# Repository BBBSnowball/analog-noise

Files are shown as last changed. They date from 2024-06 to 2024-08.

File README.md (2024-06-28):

"Completely analog" noise generator
===================================

A friends is very into analog synthesizers. I'm usually more on the digital side.
You can imagine the discussions we sometimes have about this ;-)

He recently baught [this drum synthesizer][1] that supposedly has "some digital
components" but he said that any passive module is "analog enough". What is a
passive module? Anything without a dedicated power supply, i.e. the only power
flowing into it is via its input signals.

Some time later, he mentioned that he doesn't know of any good analog noise generators.

Well.... let the trolling begin :-D

[1]: https://www.errorinstruments.com/a-85227938/bricky-format-standalone-box/po-passive-operator-drum-synth/

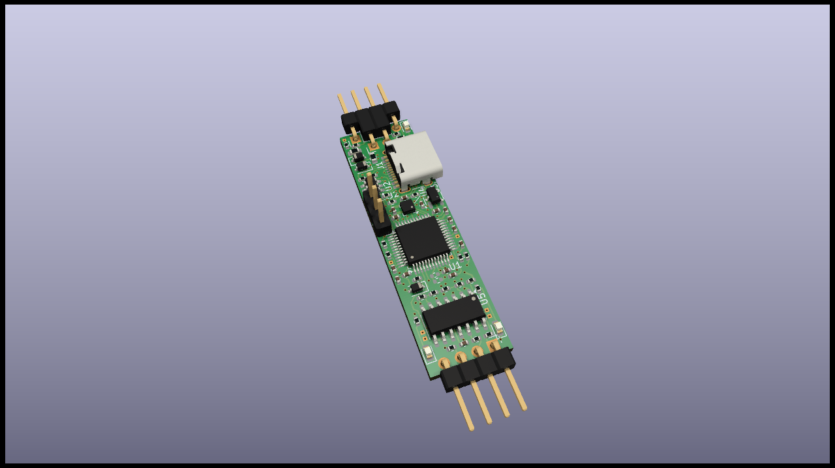
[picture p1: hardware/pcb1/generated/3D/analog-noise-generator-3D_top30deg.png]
Rendered PCB


## Plan

- MCU
    - internal oscillator (for low power)
    - put into sleep until gate input is high enough
        - TODO: How to do hysteresis? STM32F072 can compare to internal 1.2V reference or 1/4, 1/2 or 3/4
          of that. We could switch between those to adjust threshold.
    - at least to ADC channels, fast enough to sample both inputs with >=50 kHz
    - CRC32 unit might be useful for generating the noise (basically an LFSR).
    - DAC would be great but PWM is ok (but more complex because of filter).
- power: diode rectifier, LDO, MLCC
    - maybe another MLCC on Vbat (if available), MLCC [seems to be good enough][cap-discharge]
- inputs:
    - 1x gate
        - comparator to wake up MCU (IC or something simple)
        - expect +-10 V / 1 kOhm at driver; add 100R on our side
    - 2x input: 10 kOhm and filter, to ADC
    - 1x output: amplify to +-10V if possible, 10 kOhm impedance should be ok for a passive module
- optional:
    - maybe an LED
        - sadly not WS2812 because of 1 mA quiescent current
        - Use high-efficiency LEDs and reduce the current a lot.
    - maybe a button, potentiometer or encoder
    - USB - for ~~programming~~ analog configuring and trolling
    - bootloader:
        - CH23V203: pull PB8 high with VUSB (voltage divider! and solder jumper) or add a button
        - STM32F072: pull BOOT0 high
    - TRNG
    - one or more touch areas, "Theremin", also mix into the noise (if we don't have a TRNG)
        - The MCU even has dedicated hardware for that. Nice! -> Still true after switching to STM.
    - IMS :-D
        - [LIS2DH12TR](https://jlcpcb.com/partdetail/Stmicroelectronics-LIS2DH12TR/C110926)
          is cheap and only consumes some uA. Well... I guess that means yes.
        - There aren't any basic parts in the sensor category, so extended parts fee is more
          than component cost.
        - Typical sample rate ("ODR/2") seems to be 10/2 Hz or 50/2 Hz but can be as high as 5/2 kHz,
          so we could probably use this for input (tilt, then double-tap).
        - We could react to disturbance. We had lots of fun with that feature of a spring reverb :-)
    - small epaper?
        - Doesn't look like a display (i.e. not digital). Can show function of current firmware.
        - Waveshare's 1.9'' epaper has I2C but that is 7-segment, not pixels. The others are as
          complicated as the one that we have used for the Framework 16 project (and they also use
          quite a lot of pins).
        - [This one](https://www.waveshare.com/product/displays/e-paper/2.13inch-touch-e-paper-hat.htm)
          has touch (only five points), maybe a suitable case. Communication is still SPI. Maybe as an optional
          feature instead of LEDs and touch. It is rather large.
- mechanical:
    - "analog noise generator with gate": shrink tube, put in the middle of a patch cable
    - "analog multiplier with gate": Eurorack module cover (3D printed or wood), glue PCB to its back, three jacks
    - 3D printed case in cable, with two parts that can be rotated to set a value
    - LQFP-48 is 9x9 mm with pins (7 mm for body). That is larger than I would like but smaller packages
      are more expensive.

[cap-discharge]: https://www.robotroom.com/Capacitor-Self-Discharge-2.html

- How much power do we have available?
    - 10 V / 1 kOhm is 10 mA. As we use an LDO, that's also true at 3.3 V.
    - MCU need 0.5 mA to 16 mA depending on frequency, so let's stick to lower frequencies.
    - output will provide up to 1 mA at 10 kOhm impedance (plus what the amplifier needs).
    - We should expect to see up to 15 V continuous because 10 V is more like the minimum and
      many modules go up to 1..2 V below there supply of 12 V or 15 V.
- How much delay after the gate is asserted? -> not updated for STM, yet
    - Startup time for oscillator alone is 2.5 ms. Internal HSI needs 10 us.
    - Let's expect a few ms overall and hope for the best.
    - It could be a lot less if gate rises slowly (we can start up before it reaches the
      threshold). In fact, that is our goal and that's why the threshold voltage is near
      the maximum.
- Any PCBs that we can use as reference or even copy?
    - https://github.com/metro94/FlappyBoard
    - I'm not sure which things on the board may be notices according to OHL but we will
      probably only copy the schematic anyway.
    - https://github.com/Jana-Marie/OtterPill
    - Use SY8201?
        - 0.4 mA quiescent current will be 3 mW at 7 V. LDO would waste 11 mW at 7 V.
        - We would have to use lower caps.
        - LDO is simpler+cheaper and good enough, we think.
    - Well, if we use neither SY8201 nor FUSB and we use STM32 symbol from Kicad libraries,
      there isn't anything to copy from OtterPill.
- Which LDO?
    - There don't seem to be any basic parts in category power.
    - More than 15 V (with some margin). Reasonable quiescent current.
    - 5 mA would be 60 mW.
    - [LR8321A-T33](https://www.lcsc.com/product-detail/Linear-Voltage-Regulators-LDO_LR-LR-LR8321A-T33_C5129918.html),
      [vendor page](https://www.lorysemi.com/product/80b8478f710f4a6b9008f729313d2654/a9d765514f14408ab45c6008f1d1d0b4):
      100 mA, 250 mW
- Pinout planning - assuming that we use the QFN28 package. -> This was for CH32.
    - fixed:
        - 4x power
        - 2x crystal
        - 2x BOOT0, nRST  (BOOT0 can be an output after startup)
        - 2x USB
        - 2x SWD ?
        - 1x WKUP?
    - usable:
        - PA1..PA7 (ADC)
        - PB0..PB1 (ADC)
            - PA2..PB1 are also used for the opamps.
            - Touch uses the ADC pins.
            - //Can all ADC inputs be connected to either of the two ADCs? -> We only have one for STM.
        - PA9
        - PA15
        - PB3..PB7
            - PB6 and PB7 are I2C1 (and PB5). PB6 is SCL, which can also be mapped to PB8. I2C is for IMS.
            - PB5 is `I2C_SMBA` (SMBus Alert), which we don't need.
        - summary: 9x ADC, 7x GPIO (including I2C)
    - needed:
        - 2x I2C
        - 1x wakeup+gate -> PA0 (WKUP and ADC0)
        - 2x input (ADC)
        - voltage doubler / inverter
          - 2x positive and negative output rail (ADC, so we know our usable range)
          - 1x input supply (ADC)
            (wakeup is connected to unfiltered gate, i.e. not the same as current voltage in capacitor)
          - 1x inverter for negative rail (PWM)
          - 1x doubler for positive rail (PWM)
          - 2x output signal (ADC)
          - (ADC signals for rails could be used as LED outputs if we don't use high-z and keep the ADC voltages below LED Vf.)
        - 1..2x output (TIM)
        - 1x VUSB detect (BOOT0 cannot be used as an input)
            - Could be the same as e.g. a touch key (which is then not usable while VUSB is present).
        - sum so far: 15 (7 ADC)
        - 0..1x touch (ADC)
        - 4x LED ?
            - [charlieplexing](https://en.wikipedia.org/wiki/Charlieplexing)
            - 12 LEDs with 4 pins. Do we need a resistor per LED? Or half the resistor on each pin?
            - Alternative: Bidir matrix with 8 LEDs.
            - We can use BOOT0 pin but not as three-state.
        - 0x button ?
        - 1x poti ?
- Pinout planning for STM32F072CBT6 (LQFP-48):
    - fixed:
        - 1: VBAT (nice - we have that available here)
        - 3,4: OSC32
        - 5,6: OSC
        - 7: NRST
        - 8,9: analog power
        - 14, 15: DAC
        - 23, 24: power
        - 32, 33: USB
        - 34: SWDIO
        - 35, 36: power
        - 37: SWCLK
        - 44: BOOT0
        - 47, 48: power
    - usable:
        - 2, 10, 11, 12, 13, 16, 17, 18, 19, 20, 21, 22, 26..31, 38..43, 45, 46
        - 26x ^^
    - comparator:
        - outputs are fixed
        - inputs can be on several pins or Vref (1.25V or 1/4, 2/4, 3/4 of that),
          Vref can be connected to negative input
        - COMP1: input is PA1, output is PA0, which is also WKUP
        - COMP output can also go to EXTI, which is also a wakeup source from most modes.
    - I2C:
        - PB10, PB11 (I2C2)
        - PB13, PB14 (I2C2)
        - PB6, PB7   (I2C1)
        - PB8, PB9   (I2C1)
    - SPI:
        - PA4..PA7 (SPI1)
        - PB10, ..?
        - PB12..PB15 (SPI2)
            - PB13: SCK, SCL  -> IMS also has them on the same pin.
            - PB14: MISO, SDA -> IMS has SDA and MOSI on the same pin.
        - PA15 or PB9, PB3..PB5 (SPI1)

### TODO

- Can CH32V2xx run its USB bootloader from internal crystal or should we add an external one?
    - Well, let's add the external one and hopefully not use it (but it doesn't really need
      more power than HSI, to be honest).
    - STM32F072 can definetely do it without the crystal.
- Low-power OpAmp for output or transistor amplifier?
    - Rail-to-rail would be useful. That should be easier with an integrated part.
    - There are lots of low power amplifiers, e.g. [LP358][LP358]. They are below 100 uA.
      Actually, we could tolerate a bit more than that. GBW is often not great but we amplify
      by 6x for audio so ~150 kHz should be fine (or less - depending on how much we filter
      our PWM anyway).
    - The cheapest LM321 on LCSC has 1.2 to 3 mA depending on VCC. That is a bit high but
      should work.
    - The cheapest LM358 on LSCS has below 1 mA even at 36 V. That's good. Output doesn't
      go up to positive rail even at very low current.
    - Cheapest with FET input on LCSC is TL072. It needs ~~a bit over 1 mA~~ per amplifier
      (so maybe try and use the 1x variant) and it goes to within 0.2 V of the rails at
      10 kOhm. Sounds good.
    - TL082 is similar but I just noticed that supply current is 1.4 to 2.8 mA per amplifier
      and that also goes for the TL072 (the figure from before was quiescent current).
    - Well, let's use one of them anyway. That's good enough.
    - We want TL072CDT because that's the only basic part in that category! Supply current is
      2.5 mA max but output swing is 1.5 V below the rails.
    - Actually, the [basic part LM324](https://jlcpcb.com/partdetail/Stmicroelectronics-LM324DT/C71035)
      is quite low-power. How did I miss that before? It will still be 1-3 mA because it has
      4 amplifiers.
    - Downside of LM324 is that its `V_OH` is 1.5 V below the upper rail.
- Can we make a simple TRNG? What sources of entropy do we have?
    - [Infinity Noise](https://github.com/waywardgeek/infnoise) has good documentation but
      3 opamps is a bit much for us.
    - Ring oscillators, e.g. [like this](https://github.com/stnolting/neoTRNG). This is more
      for FPGA but we could use the oscillators of the MCU.
    - Tie unused ADC inputs to half VCC with high impedance.
    - Onchip temperature sensor.
    - Mix in the unique ID.
    - Store previous seed in RTC memory.
    - IMS.
- Connect VBAT?
    - //It would be nice to have the RTC available but dedicated VBAT is only available on the
      larger packages.
    - Alternative: Not much connected to 3.3V supply, diode in series to LDO. Stop and standby
      don't use more current than RTC according to datasheet. Downside: It needs programming
      discipline and we have to power down anything that we connect to that supply (or
      power it through an IO pin).
    - It is available for STM. Yes, let's connect it.
- What do we do about negative voltages?
    - We will usually get a gate signal with 0 V and 10 V, I assume. And we have GND. We can add a
      negative voltage rail but it won't usually be charged.
    - That's not so great because our opamp won't be so great near the negative rail, which will
      be GND in our case.
    - Simple switched capacitor voltage inverter to at least have -2.9 V? -> Probably a good idea.
- How much capacity for power buffer? How to connect it?
    - //Long enough to provide useful time for RTC. MCU and IMS will draw some tens of uA.
        - Starting at 3.3 V. Normal operating range is down to 2.4 V. RTC can work down to
          1.8 V (when powered through VBAT).
        - Example: 1 uF = 50uA*t/(3.3V-2.4V) => t = 0.018 sec => not so great
    - STM32: 2 uA on Vbat with LSE. Works down to at least 1.65 V.
        - Example: 1 uF =  2uA*t/(3.3V-1.65V) => t = 0.8 sec => usable but not great
        - Typical values are more like 1 uA and half that at lower voltage, i.e. let's assume 2 sec.
        - We can use more capacity but we have to be smart about charging it, e.g. GPIO -> diode and resistor -> cap -> diode -> Vbat.
        - If we have 1% duty cycle, we should charge with 100x 2 uA, i.e. 200 uA. Ok, we could do that without controlling it with a GPIO.
          8 kOhm would achieve that but draw 400 uA when the cap is empty but we will lose some
          power through it when drawing current from the cap (but voltage drop is only 20 mV,
          i.e. not an issue and a diode would lose more power).
        - So... 100 nF on Vbat plus maybe 10 uF connected via 10 kOhm.
        - What can we use it for? Store random seed and wakup main MCU (but that needs main power
          anyway).
        - Ok, let's not put too much effort here: Use LSI instead of LSE (although we have no idea
          how much power that costs). 100 nF + 10 + 1 or 10 uF
    - Long enough to switch MCU to low-power mode, e.g. a few ms. Maybe long enough to continue
      working for a few ms to compensate startup delay.
        - Let's plan with 5 mA and 10 ms.
        - Voltage can go from 10 V to 5 V but that will be noticed in the output signal, of course.
        - That would be 10 uF. That is reasonable.
        - However... how long would it take to charge this? tau = 10 ms. Not great.
    - Another issue: We cannot set our gate threshold to 8 V because we will see less voltage
      while we are drawing power or even charging the capacitor.
        - If we draw 5 mA, we will see half the voltage. Not only for the gate but also for the
          capacitor. D'oh!
        - So... it would be good to limit ourselves to 3 mA and not much capacity.
        - The gate should have a large hysteresis.
    - Options?
        - Supply for MCU by DCDC (up to 3x more efficient).
            - If we find cheap DCDCs, we could have a step-down for the MCU, step-up for real 10 V
              and inverter for -10 V. The quiescent currents will add up so that is probably not
              feasible but we can try. -> but opamp would have to be even more power efficient.
            - Step-down: [TPS560200](https://jlcpcb.com/partdetail/TexasInstruments-TPS560200DBVR/C83671)
            - Suggested capacitors are rather high (10 uF) for most DCDCs.
        - Use less power for the MCU. It needs only 0.5 mA at low frequencies.
        - Voltage doubler (and maybe a voltage inverter from the higher voltage instead of MCU pin).
        - Generate output voltage from MCU pin (0 to 3.3V range, only passive filter).
        - Generate output voltage with h-bridge plus passive filter (power consumption to be determined).
            - Example: 10 kOhm plus 5 nF (and maybe 1 kOhm to output). tau=50 us (20 kHz). Current is 1 mA
              at 100 kHz according to Falstad.
            - Even when we add a transistor as a voltage follower, we will need the 1 mA if we want
              10 kOhm output impedance.
            - We may want to add a 2nd filter stage. The one stage has a ripple of +-300 mV!
        - Generate digital signal without much of a filter (only good for hard noise).
            - We should have this as an option.
        - Use an actual low-power opamp.
        - Hope that the opamp is closer to its quiescent current than supply current because our
          signals are slow (but that is still more than 2 mA for the dual opamp).
        - Generate output voltage controlling regulated voltage doubler.
            - This can work because load on the outputs should be fairly constant.
            - To be more precise: We know capacitance at the output and we know how much we transfer
              with each cycle. Thus, we know how many cycles are need for a certain change in output
              voltage. We measure the output voltage to estimate load impedance and compensate. We
              optionally charge through a resistor for a shorter time to adjust by less than a full
              cycle. We also have to adjust for variations in input voltage if we don't use the 3.3V.
            - Downside: This will probably take 4-5 pins per output.
            - Downside: This will only get us a range of -3 to +6 or so.
            - Downside: Unless we add a H-bridge, power will come from LDO/DCDC for 3.3V, i.e. less efficient.
              (or maybe we can avoid that with just one FET and one diode per capacitor..?)
            - VCC will flow to the output through the diodes if we stop the cycles, i.e. we cannot
              output low voltages without an additional switch for VCC.
            - Can we do this with a few MX6208 (L9110 with more suitable specs for this)? -> 22 mA
              for high-z state - no.
            - Can we do it with 3.3 V and 3x GPIO? -> No.
                - [see this simulation][sim1]
                - Reason: The diodes will keep us to within 2x 0.4 V of 0 V / 3.3 V.
                - If we split the GPIO on the right, the simulation will work but ESD diodes will
                  spoil it.
    - Thus: Go with LM324. Keep current for MCU low enough. Maybe boost its supplies with voltage
      doubler / inverter (but only driven by MCU pin).
    - [Simulation][sim2]
        - We can double output swing (but asymmetric).
        - The switched capacitors need rather a lot of current on 3V3 but that shouldn't consume
          much power because the current is symmetric. The actual power comes from the higher VCC.
          We will lose 2x 6 mA in parasitic resistances, though - which should be mostly the FETs
          of the GPIO.
            - See [this simulation][sim3].
        - Startup time is roughly 5 ms, [see here][sim4].
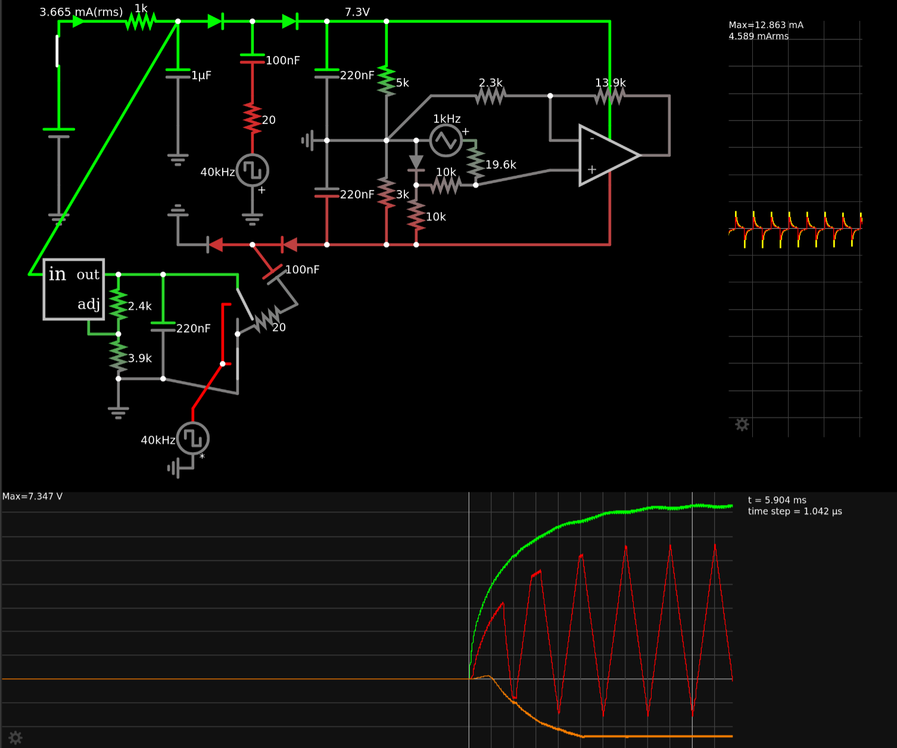
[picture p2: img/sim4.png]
            - 
        - VCVS to convert signal to PWM? [Yes, but very slow][sim5]
        - [Simulation with PWM][sim6]
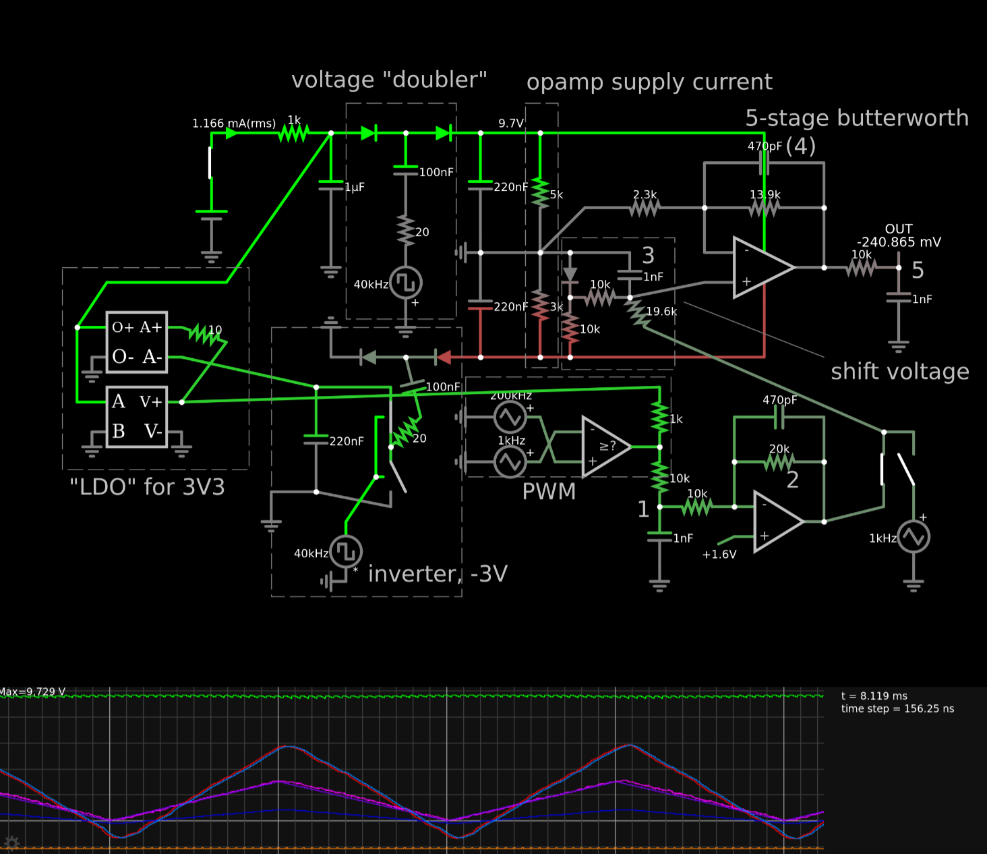
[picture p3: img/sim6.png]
            - 
            - The 4th stage of the filter doesn't really match the rest, I think.
            - We should remove the "shift voltage" part and adjust the offset in the 2nd filter stage.
            - Offset (voltage shift) and gain should be trim potis because they depend on how well the voltage doubler/inverter are working,
              i.e. we are unlikely to get it right the first time.
            - Add solder jumper for skipping the voltage doubler/inverter.
            - Pins needed:
                - 1x voltage doubler (PWM)
                - 1x inverter (PWM)
                - 2x PWM (1 per output)
                - 2x ADC for rails
                - 1x ADC for VCC
                - 2x ADC for outputs
                - That is a lot!
    - Any MCU with integrated DAC? That would be a lot easier.
        - CH32V3xx, e.g. CH32V305FBP6 for $2
        - CH32F103 for $1.60
        - APM32F072CBT6 for $1.10
        - GD32F303RCT6 for $1.40
        - STM32F072CBT6 for $1.30 - why did I not see this in my previous search? -> Sorting by price is broken.
            - $1 for >= 30 pcs. Could be ok.
        - STM32 low-power - [several series](https://www.st.com/en/microcontrollers-microprocessors/stm32-ultra-low-power-mcus.html)
            - STM32L0: Many have USB, all have 1 or 2 DAC, it seems -> no.
            - [STM32L053](https://jlcpcb.com/partdetail/Stmicroelectronics-STM32L053R8T6/C79207): USB and 1x DAC, $1.7 or $1.4 for 30 pcs
            - [STM32L072](https://jlcpcb.com/partdetail/Stmicroelectronics-STM32L072RBT6/C915968): USB and 2x DAC, $2 is too much
            - F072 is much cheaper than L072. L072 needs about half as much current (if we keep frequency low) and that could be a relevant difference.
            - U series doesn't seem to be available on JLC.
        - Ok, go with STM32L053?
    - External DAC.
        - Many are with I2S but that is only available for CH32V303 or higher. We could maybe use SPI. They also have too much supply current.
        - [GP8102](https://www.lcsc.com/product-detail/Digital-To-Analog-Converters-DACs_Guestgood-GP8102-F50-NH-SW_C5464820.html):
          PWM to analog. 2 mA. $0.80, $0.60 for 30 pcs.
        - [DAC7311](https://www.lcsc.com/product-detail/Digital-To-Analog-Converters-DACs_Texas-Instruments-DAC7311IDCKR_C128601.html):
          150 uA. $0.93, $0.7 for 30 pcs
        - That will be more expensive than larger MCU. We also have to consider cost for extended part.
        - None that I found so far could be connected to the higher voltage.
    - Ok, let's keep things simple: Use [STM32F072CBT6](https://jlcpcb.com/partdetail/Stmicroelectronics-STM32F072CBT6/C81720)
    - We should use 1 uF for the caps.
- What LDO to use?
    - We have selected an extended part, so far. Can we change that?
    - [30V, 3.3V, SOT-89-3](https://jlcpcb.com/partdetail/HoltekSemicon-HT75331/C14289) -> that would work
        - I'm not sure why I seem to have overlooked this earlier.
        - It is larger so not so easy to change it now.
    - [36V, adjustable, SOT-23](https://jlcpcb.com/partdetail/3500-CJ431/C3113) -> it is a voltage reference but 100 mA is more than enough for us
    - [36V, step-down, SOIC-8](https://jlcpcb.com/partdetail/TexasInstruments-TPS5430DDAR/C9864) -> 3 mA quiescent current is too much
- Do we use voltage doubler or inverter?
    - Too much area, too little gain - at least for voltage doubler.
    - Voltage inverter doesn't [look to great either][sim7].
    - There is an inductor basic part: [10 uH, 15 mA, 0805](https://jlcpcb.com/partdetail/Sunlord-SDFL2012S100KTF/C1046).
      That could be enough. There is also one with 3 mA in 0603.
    - 10 uH/U*I
        - at 10V, with 2 mA: 2 us
        - at 3.3V, with 2 mA: 6 us
    - [The simulation][sim8] has 7V and 100 kHz with 4% duty cycle, i.e. 0.4 us, but the inductor goes up to 27 mA. This is fishy!
    - This could probably work but we would have to simulate with NGspice or LTspice to verify.
    - Let's omit it, for now.
    - Let's keep it very simple and not even support negative gate voltage.
    - If we want to measure (but not output) negative voltage on VIN, we have to connect it to IN2.

[LP358]: https://www.ti.com/lit/ds/symlink/lp358.pdf?ts=1717468161669
[sim1]: https://falstad.com/circuit/circuitjs.html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
[sim2]: https://falstad.com/circuit/circuitjs.html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
[sim3]: https://falstad.com/circuit/circuitjs.html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
[sim4]: https://falstad.com/circuit/circuitjs.html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
[sim5]: https://falstad.com/circuit/circuitjs.html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
[sim6]: https://falstad.com/circuit/circuitjs.html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
[sim7]: https://falstad.com/circuit/circuitjs.html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
[sim8]: https://falstad.com/circuit/circuitjs.html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

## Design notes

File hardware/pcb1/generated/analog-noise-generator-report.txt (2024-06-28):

# PCB

Board size: 12.7x45.59 mm (0.5x1.8 inches)

- This is the size of the rectangle that contains the board
- Thickness: 1.6 mm (63 mils)
- Material: FR4
- Finish: None
- Layers: 4
- Copper thickness: 35 µm

Solder mask: TOP / BOTTOM

- Color: Green

Silk screen: TOP / BOTTOM

- Color: White

Stackup:

| Name | Type | Color | Thickness | Material | Epsilon_r | Loss tangent |
|---|---|---|---|---|---|---|
| F.SilkS | Top Silk Screen | | | | | |
| F.Paste | Top Solder Paste | | | | | |
| F.Mask | Top Solder Mask | | 10 | | | |
| F.Cu | copper | | 35 | | | |
| dielectric 1 | prepreg | | 100 | FR4 | 4.5 | 0.020 |
| In1.Cu | copper | | 35 | | | |
| dielectric 2 | core | | 1240 | FR4 | 4.5 | 0.020 |
| In2.Cu | copper | | 35 | | | |
| dielectric 3 | prepreg | | 100 | FR4 | 4.5 | 0.020 |
| B.Cu | copper | | 35 | | | |
| B.Mask | Bottom Solder Mask | | 10 | | | |
| B.Paste | Bottom Solder Paste  | | | | | |
| B.SilkS | Bottom Silk Screen | | | | | |

# Important sizes

Clearance: 0.13 mm (5 mils)

Track width: 0.13 mm (5 mils)

- By design rules: 0.13 mm (5 mils)

Drill: 0.4 mm (16 mils)

- Vias: 0.4 mm (16 mils) [Design: 0.4 mm (16 mils)]
- Pads: 0.4 mm (16 mils)
- The above values are real drill sizes, they add 0.1 mm (4 mils) to plated holes (PTH)

Via: 0.5/0.3 mm (20/12 mils)

- By design rules: 0.2/0.3 mm (8/12 mils)
- Micro via: yes [0.2/0.1 mm (8/4 mils)]
- Buried/blind via: yes
- Total: 101 (thru: 101 buried/blind: 0 micro: 0)

Outer Annular Ring: 0.05 mm (2 mils)

- By design rules: 0.11 mm (4 mils)

Eurocircuits class: 7D
- Using min drill 0.25 mm for an OAR of 0.13 mm

# General stats

Components count: (SMD/THT)

- Top: 55/4 (SMD + THT)
- Bottom: 7/0 (SMD)

Defined tracks:

- 0.09 mm (4 mils)
- 0.13 mm (5 mils)
- 0.2 mm (8 mils)
- 0.3 mm (12 mils)
- 0.4 mm (16 mils)
- 0.5 mm (20 mils)

Used tracks:

- 0.13 mm (5 mils) (5) defined: yes
- 0.2 mm (8 mils) (745) defined: yes
- 0.3 mm (12 mils) (172) defined: yes
- 0.4 mm (16 mils) (37) defined: yes

Defined vias:

Used vias:

- 0.5/0.3 mm (20/12 mils) (Count: 100, Aspect: 3.2 A) defined: no
- 0.6/0.3 mm (24/12 mils) (Count: 1, Aspect: 2.7 A) defined: no

Holes (excluding vias):

- 0.3 mm (12 mils) (8)
- 0.65 mm (26 mils) (2)
- 1.0 mm (39 mils) (13)

Oval holes:

- 0.6x1.2 mm (24x47 mils) (2)
- 0.6x1.7 mm (24x67 mils) (2)

Drill tools (including vias and computing adjusts and rounding):

- 0.4 mm (16 mils) (109)
- 0.65 mm (26 mils) (2)
- 0.7 mm (28 mils) (4)
- 1.1 mm (43 mils) (13)

# Schematic

Schematic in SVG format

# PCB Layers

PCB Front copper

PCB Bottom copper

PCB Front courtyard area

PCB Bottom documentation

PCB Front documentation

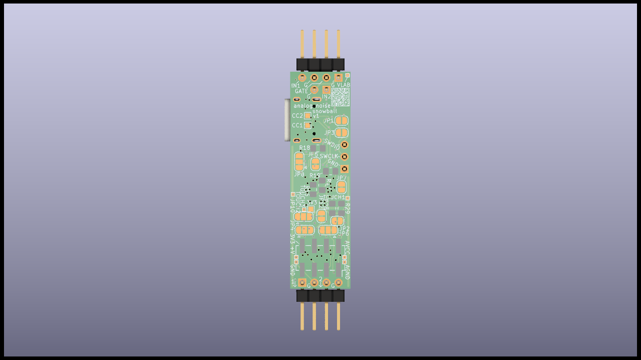
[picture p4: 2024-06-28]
hardware/pcb1/generated/3D/analog-noise-generator-3D_bottom.png

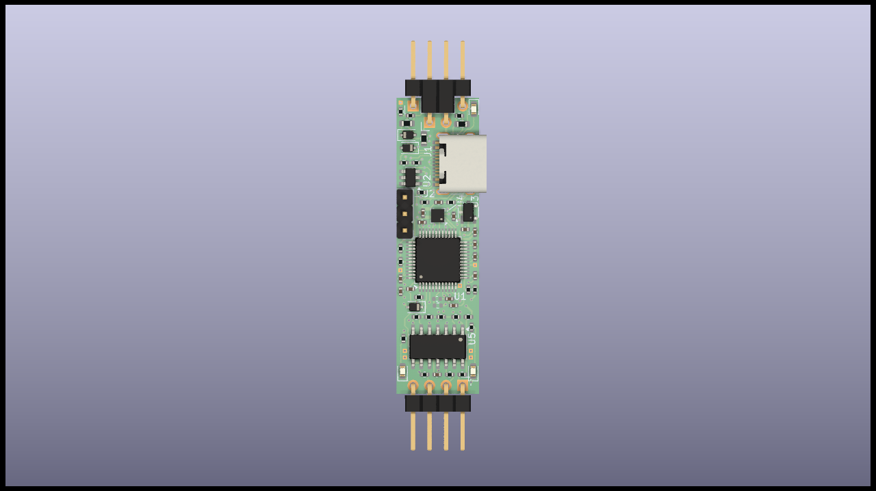
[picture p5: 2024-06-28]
hardware/pcb1/generated/3D/analog-noise-generator-3D_top.png

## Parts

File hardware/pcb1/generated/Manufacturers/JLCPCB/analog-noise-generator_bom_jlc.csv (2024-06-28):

Comment | Designator | Footprint | LCSC Part #
220p | C13,C14,C15,C18 | C_0402_1005Metric | C1530
100n | C1,C2,C3,C4,C5,C11 | C_0402_1005Metric | C1525
50V, 100.01 nF | C12 | C_0402_1005Metric | C307331
1u, 25V | C20,C21 | C_0402_1005Metric | C52923
2u2, 4V | C8 | C_0402_1005Metric | C12530
10u, 4V | C6 | C_0402_1005Metric | C15525
red | D7 | LED_0603_1608Metric | C2286
white | D5 | LED_0603_1608Metric | C2290
yellow | D6 | LED_0603_1608Metric | C72038
~ | D1,D3,D4 | D_SOD-323 | C191023
Conn_01x03_Pin | J2 | PinHeader_1x03_P2.54mm_Vertical
USB_C_Receptacle_USB2.0 | J1 | USB_C_Receptacle_HRO_TYPE-C-31-M-12 | C165948
100R | R5 | R_0402_1005Metric | C25076
1k | R33 | R_0402_1005Metric | C11702
2k2 | R34,R35 | R_0402_1005Metric | C25879
5.1k | R1,R2,R6,R9 | R_0402_1005Metric | C25905
10k | R3,R4,R7,R13,R15,R20,R21,R22,R23,R24,R27,R30,R31,R32 | R_0402_1005Metric | C25744
20k | R10 | R_0402_1005Metric | C25765
68k | R14,R25,R26 | R_0603_1608Metric | C23231
LIS2DH12 | U4 | LGA-12_2x2mm_P0.5mm | C110926
LM324 | U5 | SOIC-14_3.9x8.7mm_P1.27mm | C71035
LR8321A-T33 | U3 | SOT-23-3 | C5129918
STM32F072CBTx | U1 | LQFP-48_7x7mm_P0.5mm | C81720
USBLC6-2SC6 | U2 | SOT-23-6 | C5180279

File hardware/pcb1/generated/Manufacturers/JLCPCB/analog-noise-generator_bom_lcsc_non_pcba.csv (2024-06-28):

Comment | Designator | Footprint | LCSC Part # | DNP reason
Conn_01x02_Pin | J7 | PinHeader_1x02_P2.54mm_Horizontal |  | PCBA
Conn_01x04_Pin | J5,J6 | PinHeader_1x04_P2.54mm_Horizontal |  | PCBA

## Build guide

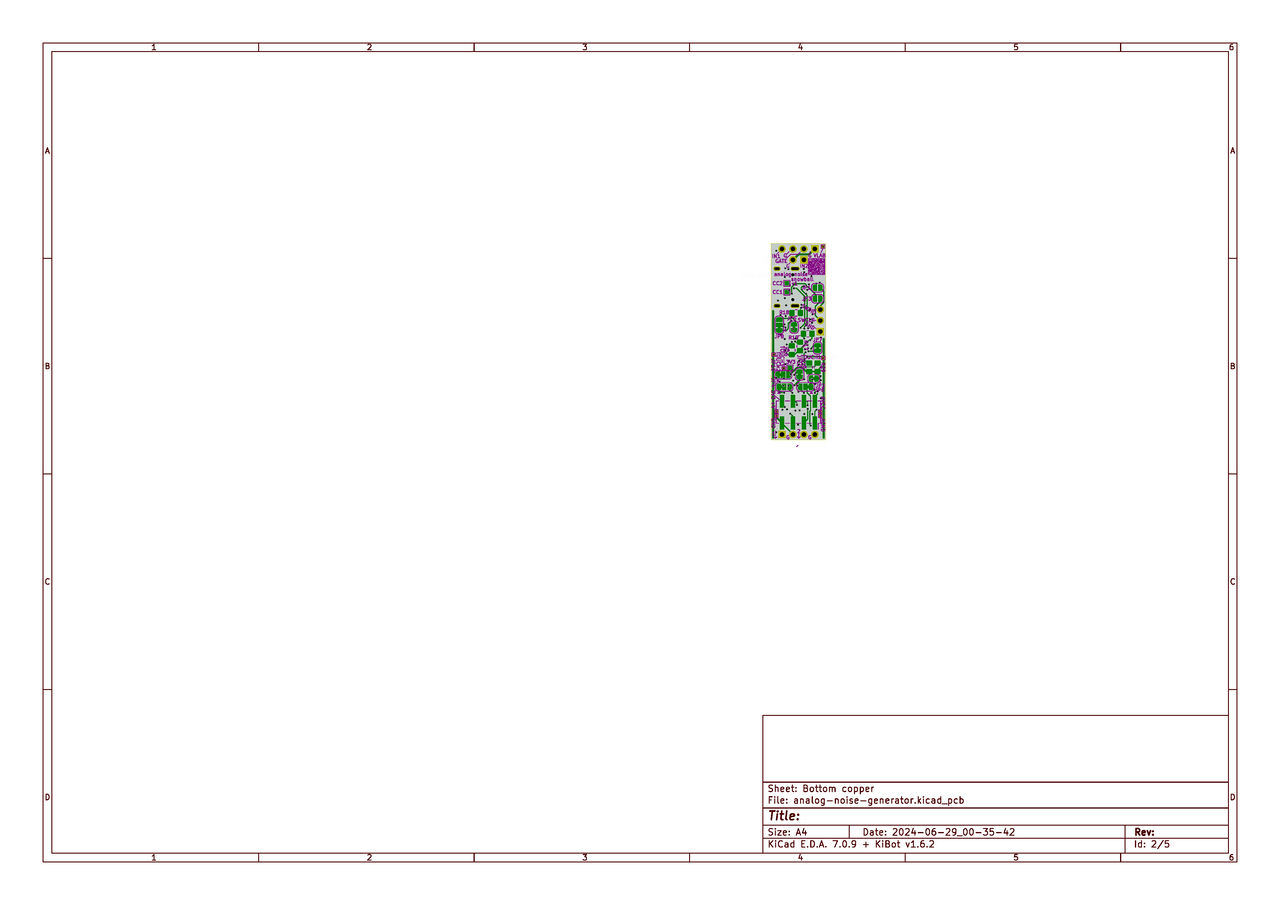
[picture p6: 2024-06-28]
hardware/pcb1/generated/PCB/PNG/analog-noise-generator-assembly_page_02.png

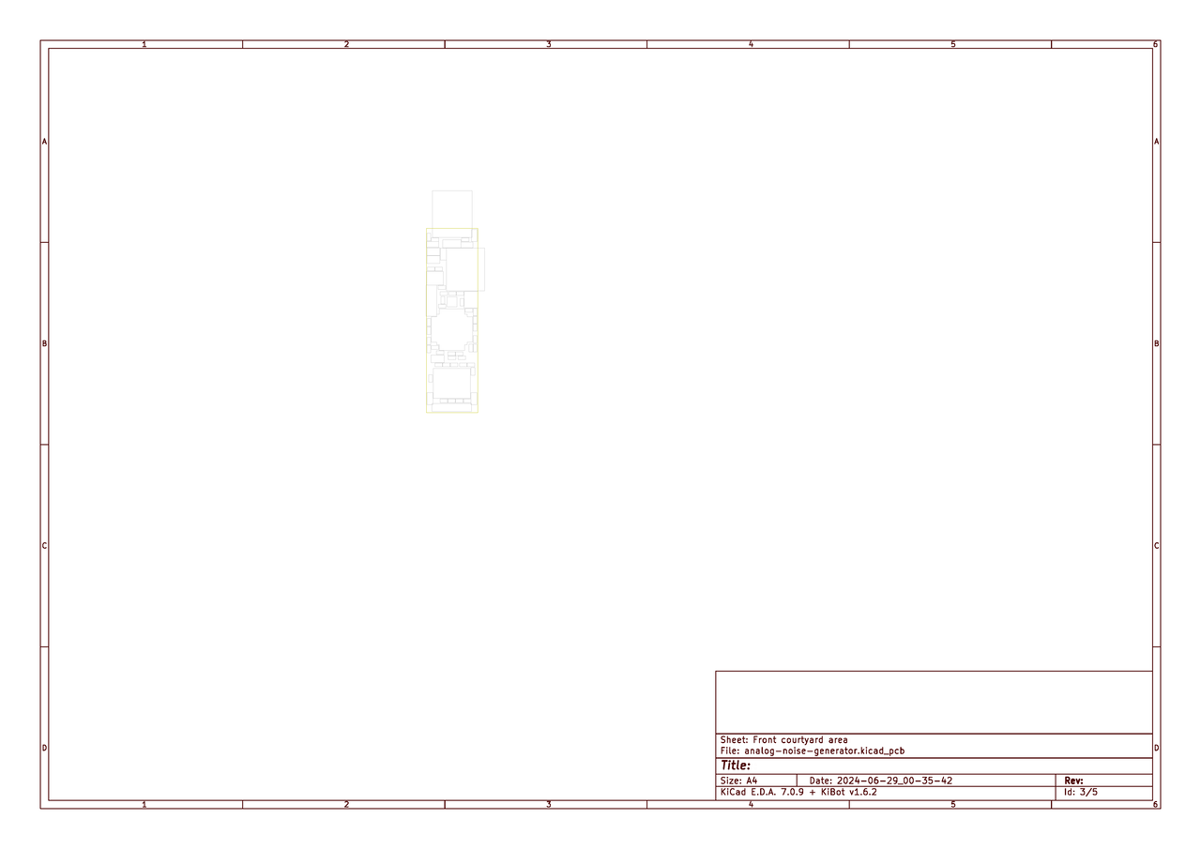
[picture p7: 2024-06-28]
hardware/pcb1/generated/PCB/PNG/analog-noise-generator-assembly_page_03.png

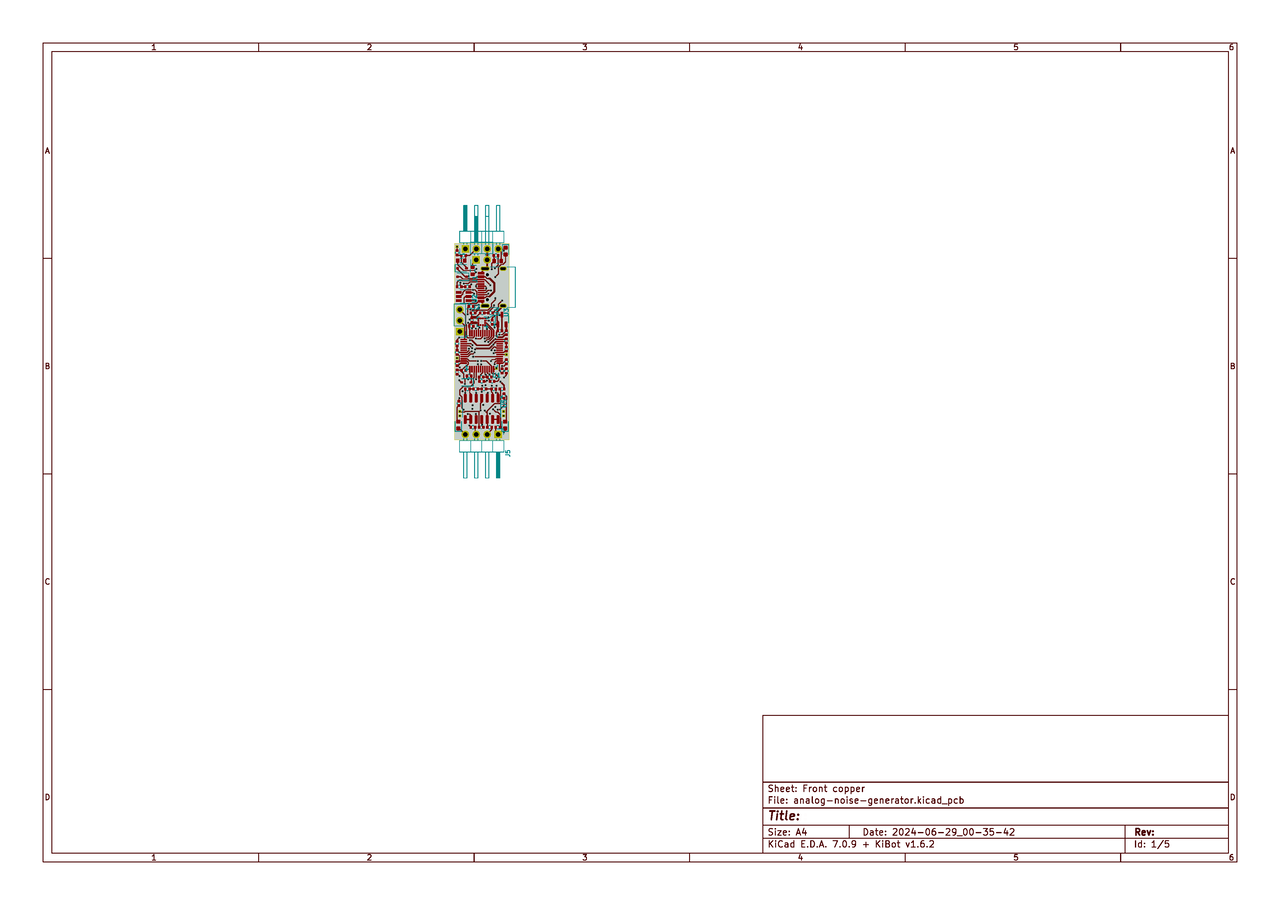
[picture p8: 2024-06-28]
hardware/pcb1/generated/PCB/PNG/analog-noise-generator-assembly_page_01.png

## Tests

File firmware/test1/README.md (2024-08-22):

```
rustup target add thumbv6m-none-eabi
#cargo install cargo-binutils cargo-bloat
cargo build
```

SVD file is from:
https://github.com/stm32-rs/stm32-rs/blob/master/svd/vendor/en.stm32f0_svd.zip

## Debugging

- use Raspberry Pico as the debug probe: SWCLK on pin 2, SWDIO on pin 3
    - There is a GND next to pin 2 so this exactly matches the order on our pin header - which is a lucky accident.
    - We couldn't find any official documentation on the pinout (the linked guides are for Raspberry Pi, not Pico)
      but it is [in the source code](https://github.com/raspberrypi/debugprobe/blob/master/include/board_pico_config.h).
    - Firmware is available [in releases of that project](https://github.com/raspberrypi/debugprobe/releases/tag/debugprobe-v2.0.1):
      `picotool load ~/Downloads/debugprobe_on_pico.uf2`
- start VS Code under `nix develop .#rust`
- install Cortex-Debug extension in VS Code
- start the debug configuration from `launch.json`

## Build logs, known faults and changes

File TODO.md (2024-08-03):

# PCB

These have not been implemented in what is now v1 of the board, so they probably never will be implemented ;-)

- more testpoints
    - SMD testpoints for unused pins of MCU
    - DAC
    - Vsense
    - WKUP
    - 3V3 for poti
- doch die L Variante vom MCU? -> ne, aktuell nur im großen Package verfügbar

# Potential Errata

1. We couldn't flash any firmware with ST bootloader. Is that an error in the hardware..?
    - The bootloader is enumerated and dfu-util can query its memory ranges, so most of USB is working.
      Also, USB CDC example is working fine. DFU hangs when erasing flash.
    - The normal dfu-util should support STM32F0 if we pass it an address with `-s` (which we do).
    - Some boards have 27R in USB data lines but many have 0R, so our lack of them should be fine.
    - Bluepill has pullup on one of the USB data lines but enumeration works, so this should be fine.
    - We found some mention that HSE is used for the bootloader and we don't have any external crystal.
      Again, enumeration should not work if that was the issue and schematic for STM32F072B-DISCO also
      omits the crystal.
    - We are out of ideas here, for now.
2. White LED is brighter than the others.
3. Touch sensing (TSC) needs one capacitor per group.
    - Workaround: We expected it to be similar to touch sensing on AVR and it seems to be possible
      to do it like that: https://github.com/arpruss/ADCTouchSensor
    - Downside of that workaround: It is probably less sensitive and we would rather use the ADC for
      the input signals.
    - If we fix this for v2, we have many more pins that we can use (not only ADC) but we don't have
      any free pins for the sampling capacitors in the existing groups, i.e. pinout will have to change.
    - We can add capacitors to PA0 (challenging) and PA7 (easy) on the v1 board and then use TOUCH1 and TOUCH3.
    - Can we compare TOUCH1 to TOUCH2, with both of them floating without any capacitor?
      -> No, resulting value is just 2 or 3.
4. PWM for all LEDs.
    - Use PB5 instead of PB2.
    - PB3 uses TIM2, which is not available for PWM in the hal, for some reason.
5. R3 should be 1k instead of 10 k but it is only used for testing.
6. Power consumption is higher than expected.
    - 4-5 mA with opamp disabled and MCU in `wfi()` sleep mode.
7. Glitch on DAC at startup.
    - Both DAC outputs glitch high for a short time (< 5 us) when starting up.
    - TODO: This was without the opamp. How does it behave with the opamp?
8. Output filter.
    - We should add a capacitor after R20 and R21, e.g. 1 nF for 16 kHz.

# Test Hardware

- Use interrupt for IMS.
- Test single and double click with IMS.
- PWM for the LEDs if possible.
- Add capactors for TSC to PA0 and PA7.
    - [This page](https://wiki.st.com/stm32mcu/wiki/Introduction_to_touch_sensing_with_STM32) says typical
      range is 22 nF to 220 nF.
- Test `VUSB_DET`.
- Test `VIN_SENSE`, `V+_SENSE`, IN1, IN2
- Test comparator for `VIN_SENSE`
- Test DAC1 and DAC2
- Implement low-power mode and test with limit input power.
- Use CRC unit to generate noise.
- Test with EPD.
- First application:
    - Generate noise.
    - Disable output when gate VIN is gone and go to very low-power mode.
    - Measure startup delay and maybe compensate when turning off.
    - Use IMS do control color of noise (and maybe touch so it changes when touched).

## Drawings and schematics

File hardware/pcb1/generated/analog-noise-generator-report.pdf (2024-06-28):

## PCB

Board size: 12.7x45.59 mm (0.5x1.8 inches)

- This is the size of the rectangle that contains the board
- Thickness: 1.6 mm (63 mils)
- Material: FR4
- Finish: None
- Layers: 4
- Copper thickness: 35 µm

Solder mask: TOP / BOTTOM

- Color: Green

Silk screen: TOP / BOTTOM

- Color: White

Stackup:

Name | Type | Color | ThicknessMaterial | Epsilon_r

Loss
tangent
F.SilkS | Top Silk
| Screen
F.Paste | Top Solder
| Paste
F.Mask | Top Solder
| Mask | 10
F.Cu | copper | 35
dielectric 1 | prepreg | 100 | FR4 | 4.5 | 0.020
In1.Cu | copper | 35
dielectric 2 | core | 1240 | FR4 | 4.5 | 0.020
In2.Cu | copper | 35
dielectric 3 | prepreg | 100 | FR4 | 4.5 | 0.020
B.Cu | copper | 35
B.Mask | Bottom
| Solder
| Mask | 10
B.Paste | Bottom
| Solder
| Paste
B.SilkS | Bottom Silk
| Screen

## Important sizes

Clearance: 0.13 mm (5 mils)

1

Track width: 0.13 mm (5 mils)

- By design rules: 0.13 mm (5 mils)

Drill: 0.4 mm (16 mils)

- Vias: 0.4 mm (16 mils) [Design: 0.4 mm (16 mils)]
- Pads: 0.4 mm (16 mils)
- The above values are real drill sizes, they add 0.1 mm (4 mils) to plated holes (PTH)

Via: 0.5/0.3 mm (20/12 mils)

- By design rules: 0.2/0.3 mm (8/12 mils)
- Micro via: yes [0.2/0.1 mm (8/4 mils)]
- Buried/blind via: yes
- Total: 101 (thru: 101 buried/blind: 0 micro: 0)

Outer Annular Ring: 0.05 mm (2 mils)

- By design rules: 0.11 mm (4 mils)

Eurocircuits class: 7D - Using min drill 0.25 mm for an OAR of 0.13 mm

## General stats

Components count: (SMD/THT)

- Top: 55/4 (SMD + THT)
- Bottom: 7/0 (SMD)

Defined tracks:

- 0.09 mm (4 mils)
- 0.13 mm (5 mils)
- 0.2 mm (8 mils)
- 0.3 mm (12 mils)
- 0.4 mm (16 mils)
- 0.5 mm (20 mils)

Used tracks:

- 0.13 mm (5 mils) (5) defined: yes
- 0.2 mm (8 mils) (745) defined: yes
- 0.3 mm (12 mils) (172) defined: yes
- 0.4 mm (16 mils) (37) defined: yes

Defined vias:

Used vias:

- 0.5/0.3 mm (20/12 mils) (Count: 100, Aspect: 3.2 A) defined: no
- 0.6/0.3 mm (24/12 mils) (Count: 1, Aspect: 2.7 A) defined: no

2

Holes (excluding vias):

- 0.3 mm (12 mils) (8)
- 0.65 mm (26 mils) (2)
- 1.0 mm (39 mils) (13)

Oval holes:

- 0.6x1.2 mm (24x47 mils) (2)
- 0.6x1.7 mm (24x67 mils) (2)

Drill tools (including vias and computing adjusts and rounding):

- 0.4 mm (16 mils) (109)
- 0.65 mm (26 mils) (2)
- 0.7 mm (28 mils) (4)
- 1.1 mm (43 mils) (13)

## Schematic

Schematic in SVG format

Figure 1: Schematic in SVG format

## PCB Layers

3

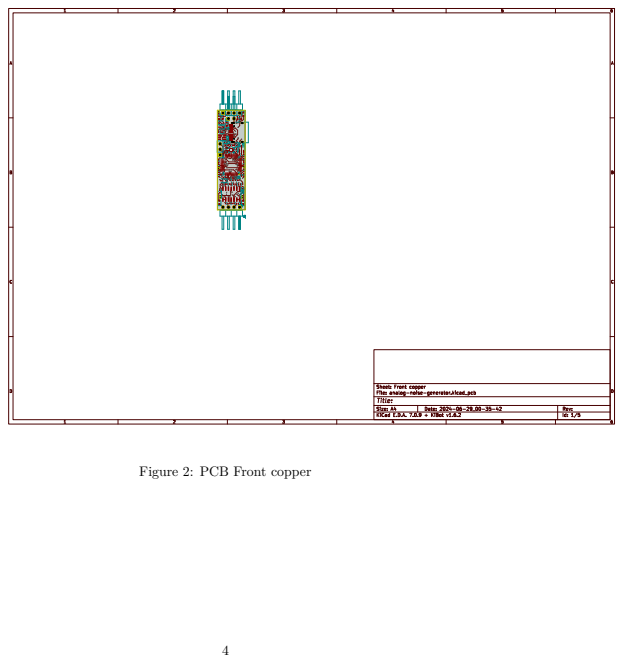
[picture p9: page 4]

Figure 2: PCB Front copper

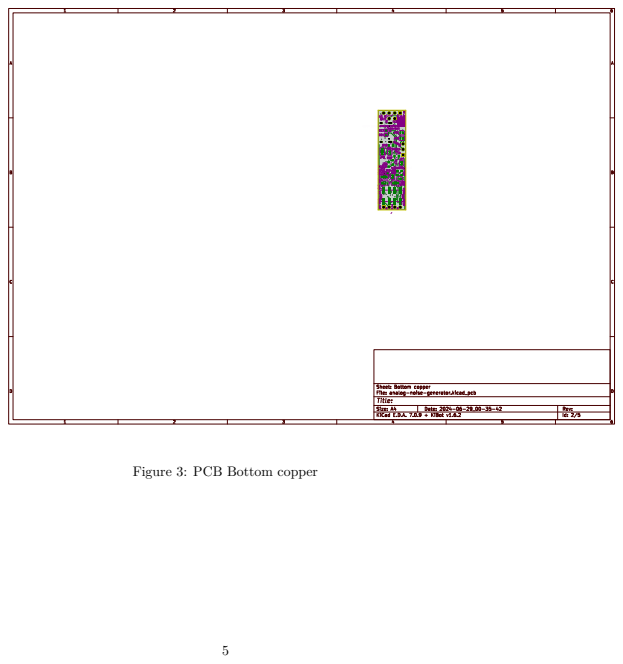
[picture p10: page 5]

Figure 3: PCB Bottom copper

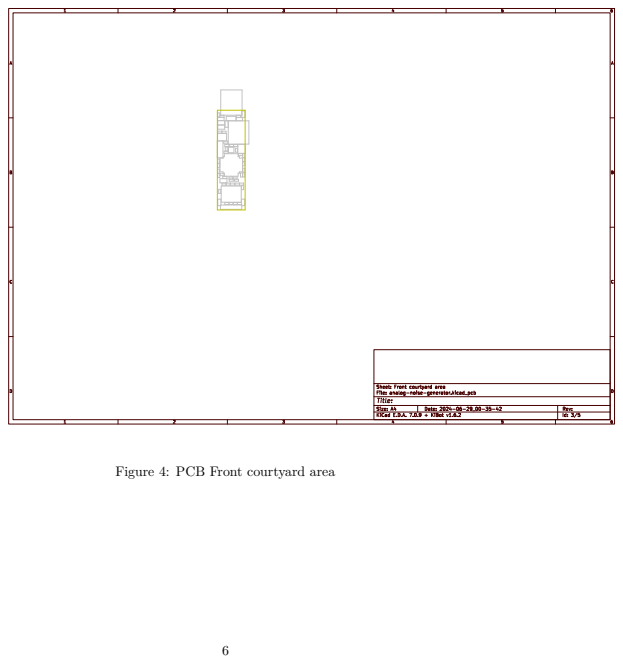
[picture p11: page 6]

Figure 4: PCB Front courtyard area

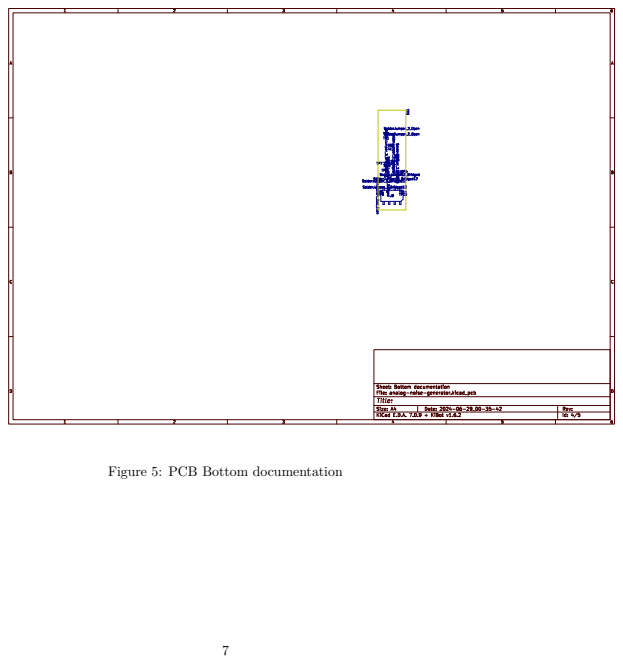
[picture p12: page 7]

Figure 5: PCB Bottom documentation

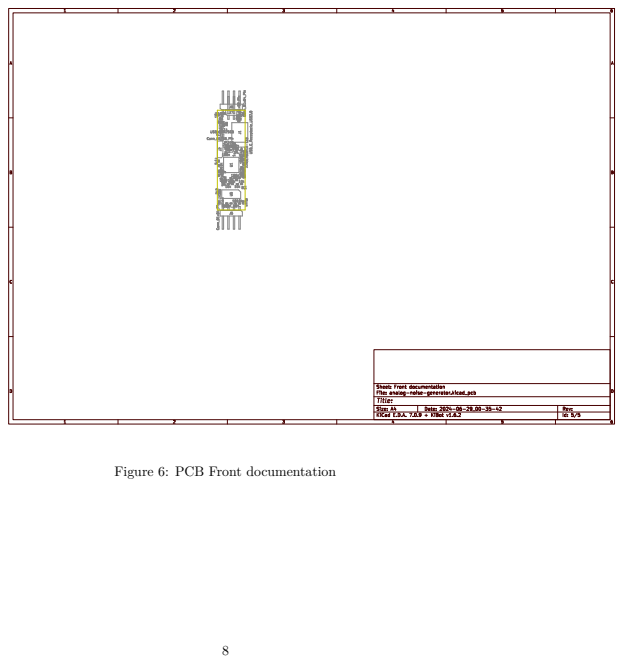
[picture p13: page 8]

Figure 6: PCB Front documentation

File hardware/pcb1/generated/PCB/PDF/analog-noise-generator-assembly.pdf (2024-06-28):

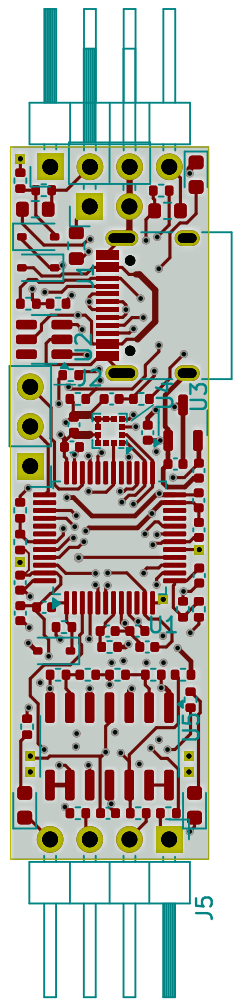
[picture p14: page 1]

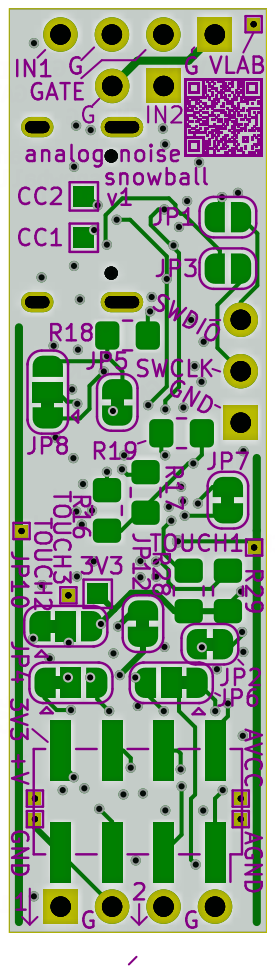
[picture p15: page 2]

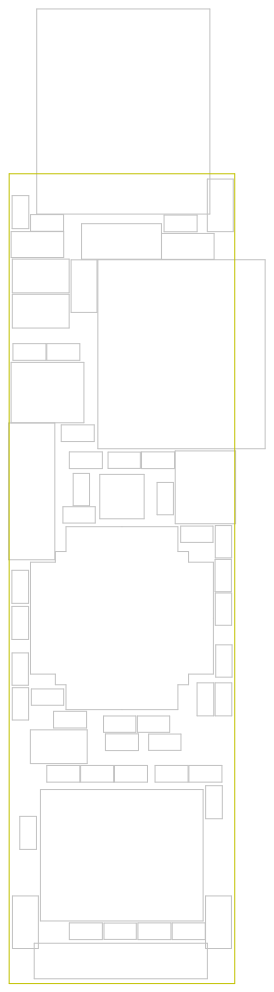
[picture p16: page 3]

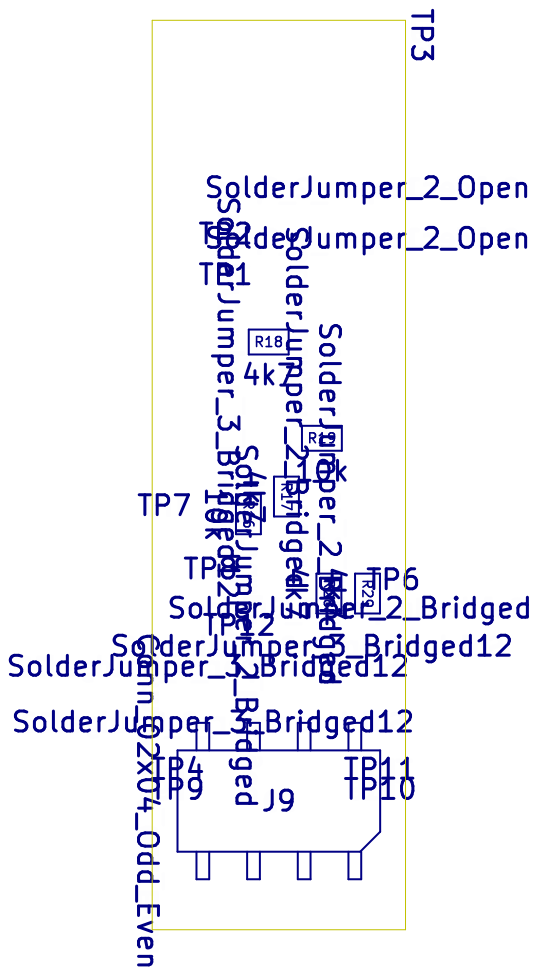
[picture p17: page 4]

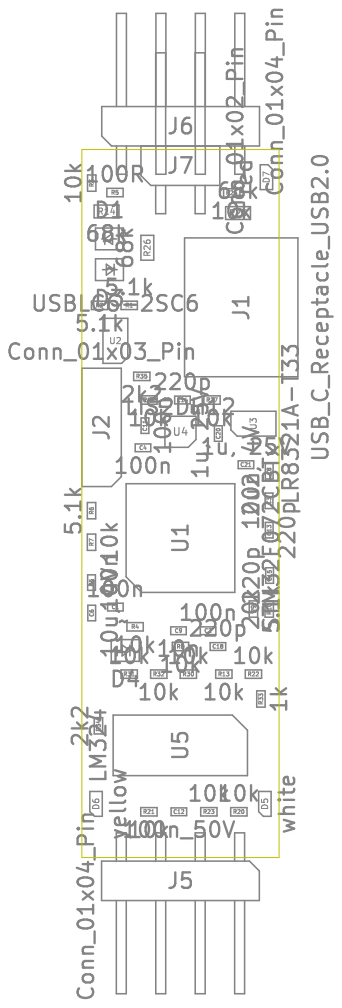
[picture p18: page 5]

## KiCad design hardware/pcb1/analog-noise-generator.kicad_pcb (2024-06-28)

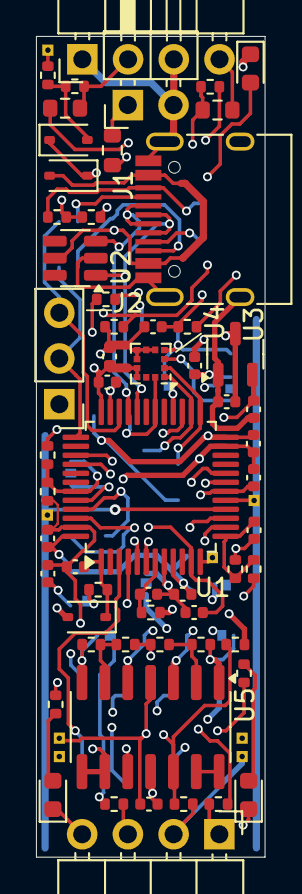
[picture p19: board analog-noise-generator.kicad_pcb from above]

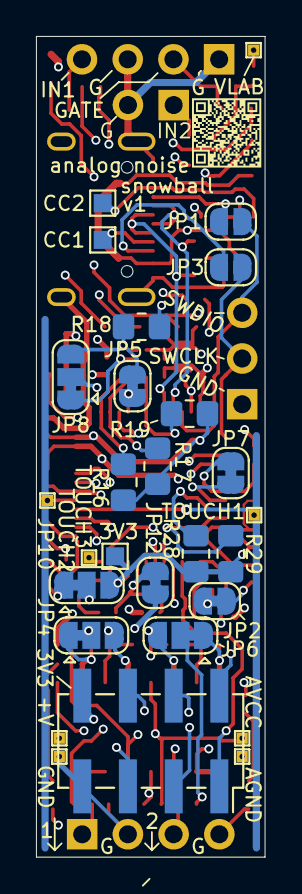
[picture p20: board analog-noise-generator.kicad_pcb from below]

Board: 4 copper layers, 12.7 x 45.6 mm, 90 parts (29 on the bottom side), 66 nets.

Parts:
C1, C2, C3, C4, C5, C11: 100n; C_0402_1005Metric
C6: 10u, 4V; C_0402_1005Metric
C8: 2u2, 4V; C_0402_1005Metric
C9: 10n; C_0402_1005Metric
C12: 100n_50V; C_0402_1005Metric
C13, C14, C15, C18: 220p; C_0402_1005Metric
C20, C21: 1u, 25V; C_0402_1005Metric
D1, D3, D4: D_SOD-323
D5: white; LED_0603_1608Metric
D6: yellow; LED_0603_1608Metric
D7: red; LED_0603_1608Metric
J1: USB_C_Receptacle_USB2.0; USB_C_Receptacle_HRO_TYPE-C-31-M-12
J2: Conn_01x03_Pin; PinHeader_1x03_P2.54mm_Vertical
J5, J6: Conn_01x04_Pin; PinHeader_1x04_P2.54mm_Horizontal
J7: Conn_01x02_Pin; PinHeader_1x02_P2.54mm_Horizontal
J9: Conn_02x04_Odd_Even; PinSocket_2x04_P2.54mm_Vertical_SMD
JP1, JP3: SolderJumper_2_Open; SolderJumper-2_P1.3mm_Open_RoundedPad1.0x1.5mm
JP2, JP5, JP7, JP12: SolderJumper_2_Bridged; SolderJumper-2_P1.3mm_Bridged_RoundedPad1.0x1.5mm
JP4, JP6, JP8, JP10: SolderJumper_3_Bridged12; SolderJumper-3_P1.3mm_Bridged12_RoundedPad1.0x1.5mm
NT1, NT2: NetTie_2; NetTie-2_SMD_Pad0.5mm
QR1: QR_git_3.8
R1, R2, R6, R9: 5.1k; R_0402_1005Metric
R3, R4, R7, R8, R13, R15, R20, R21, R22, R23, R24, R27, R30, R31, R32: 10k; R_0402_1005Metric
R5: 100R; R_0402_1005Metric
R10: 20k; R_0402_1005Metric
R14, R25, R26: 68k; R_0603_1608Metric
R16, R19: 10k; R_0805_2012Metric_Pad1.20x1.40mm_HandSolder
R17, R18, R28, R29: 4k7; R_0805_2012Metric_Pad1.20x1.40mm_HandSolder
R33: 1k; R_0402_1005Metric
R34, R35: 2k2; R_0402_1005Metric
TP1: CC1; TestPoint_Pad_1.0x1.0mm
TP2: CC2; TestPoint_Pad_1.0x1.0mm
TP3: VLAB; TestPoint_THTPad_small
TP4: +V; TestPoint_THTPad_small
TP6: TOUCH1; TestPoint_THTPad_small
TP7: TOUCH2; TestPoint_THTPad_small
TP8: TOUCH3; TestPoint_THTPad_small
TP9: GND; TestPoint_THTPad_small
TP10: AGND; TestPoint_THTPad_small
TP11: AVCC; TestPoint_THTPad_small
TP12: 3V3; TestPoint_Pad_1.0x1.0mm
U1: STM32F072CBTx; LQFP-48_7x7mm_P0.5mm
U2: USBLC6-2SC6; SOT-23-6
U3: LR8321A-T33; SOT-23-3
U4: LIS2DH12; LGA-12_2x2mm_P0.5mm
U5: LM324; SOIC-14_3.9x8.7mm_P1.27mm

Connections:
+3.3V: C2.1, C3.1, C4.1, C5.1, C8.1, C11.1, D4.2 (A), J9.8, JP10.3 (B), NT2.1, R8.2, R16.2, R17.2, R18.2, R19.2, R22.1, R28.2, R29.2, TP12.1, U1.9 (VDDA), U1.24 (VDD), U1.36 (VDDIO2), U1.48 (VDD), U3.2 (VO)
+8V: C20.1, C21.1, D1.1 (K), D3.1 (K), JP10.1 (A), R10.2, TP4.1, U3.3 (VI)
+BATT: C1.1, D4.1 (K), R4.2, U1.1 (VBAT)
/AGND: C12.2, JP12.2 (B), TP10.1, U5.11 (V-)
/AVCC: C12.1, JP10.2 (C), TP11.1, U5.4 (V+)
/BOOT0: JP7.2 (B), U1.44 (BOOT0)
/DAC1: JP4.3 (B), U1.14 (PA4), U5.3 (+)
/DAC2: JP6.3 (B), U1.15 (PA5), U5.5 (+)
/EPD_BUSY: J9.1, U1.3 (PC14)
/EPD_CS: J9.4, U1.4 (PC15)
/EPD_DC: J9.3, U1.6 (PF1)
/EPD_RES: J9.2, U1.5 (PF0)
/IMS_3V3: NT2.2, U4.9 (Vdd), U4.10 (Vdd_IO)
/IMS_GND: C14.2, NT1.1, U4.5 (RES), U4.6 (GND), U4.7 (GND), U4.8 (GND)
/IMS_INT: R19.1, U1.30 (PA9), U4.12 (INT1)
/IMS_SDI: JP5.2 (B), JP8.3 (B), R18.1, U4.4 (SDA/SDI)
/IMS_SDO: JP8.1 (A), U4.3 (SA0/SDO)
/IMS_nCS: R16.1, U1.25 (PB12), U4.2 (~CS)
/IN1: J6.4, R25.1
/IN1L: C13.1, R24.1, R25.2, U1.18 (PB0)
/IN2: J7.1, R26.1
/IN2L: C14.1, R26.2, R27.1, U1.19 (PB1)
/LED1: R33.1, U1.20 (PB2)
/LED2: R34.1, U1.40 (PB4)
/LED3: R35.1, U1.39 (PB3)
/MISO: JP8.2 (C), U1.27 (PB14)
/MOSI: J9.6, JP5.1 (A), U1.28 (PB15)
/NRST: C9.1, R8.1, U1.7 (NRST)
/OUT1: J5.1, R20.2
/OUT2: J5.3, R21.2
/SBU1: J1.A8 (SBU1), JP1.2 (B)
/SBU2: J1.B8 (SBU2), JP3.2 (B)
/SCK: J9.5, R17.1, U1.26 (PB13), U4.1 (SCL/SPC)
/SCL: R28.1, U1.45 (PB8)
/SDA: R29.1, U1.46 (PB9)
/SWCLK: J2.2, JP3.1 (A), U1.37 (PA14)
/SWDIO: J2.3, JP1.1 (A), U1.34 (PA13)
/TOUCH1: TP6.1, U1.16 (PA6)
/TOUCH2: TP7.1, U1.17 (PA7)
/TOUCH3: TP8.1, U1.12 (PA2)
/USB_D+: J1.A6 (D+), J1.B6 (D+), U1.33 (PA12), U2.3 (I/O2)
/USB_D-: J1.A7 (D-), J1.B7 (D-), U1.32 (PA11), U2.1 (I/O1)
/V+_sense: C15.1, R9.1, R10.1, U1.13 (PA3)
/VIN: D1.2 (A), R3.2, R5.2
/VIN': J6.2, R5.1, R14.2
/VIN_sense: C18.1, R14.1, R15.2, U1.11 (PA1)
/VUSB_DET: JP7.1 (A), R6.2, R7.2, U1.43 (PB7)
/Vmiddle: R24.2, R27.2, U5.8, U5.9 (-)
GND: C1.2, C2.2, C3.2, C4.2, C5.2, C6.2, C8.2, C9.2, C11.2, C13.2, C15.2, C18.2, C20.2, C21.2, D5.1 (K), D6.1 (K), D7.1 (K), J1.A1 (GND), J1.A12 (GND), J1.B1 (GND), J1.B12 (GND), J1.S1 (SHIELD), J2.1, J5.2, J5.4, J6.1, J6.3, J7.2, J9.7, JP12.1 (A), NT1.2, R1.2, R2.2, R7.1, R9.2, R15.1, R23.1, R30.2, R32.2, TP9.1, U1.8 (VSSA), U1.23 (VSS), U1.35 (VSS), U1.47 (VSS), U2.2 (GND), U3.1 (GND)
unnamed: D5.2 (A), R33.2
unnamed: D6.2 (A), R34.2
unnamed: D7.2 (A), R35.2
unnamed: J1.A5 (CC1), R1.1, TP1.1
unnamed: J1.B5 (CC2), R2.1, TP2.1
unnamed: C6.1, JP2.1 (A)
unnamed: JP2.2 (B), R4.1
unnamed: JP4.1 (A), R13.2, U5.1
unnamed: JP4.2 (C), R20.1
unnamed: JP6.1 (A), R31.2, U5.7
unnamed: JP6.2 (C), R21.1
unnamed: R3.1, TP3.1
unnamed: R13.1, R30.1, U5.2 (-)
unnamed: R31.1, R32.1, U5.6 (-)
unnamed: R22.2, R23.2, U5.10 (+), U5.12 (+)
unnamed: U5.13 (-), U5.14
VBUS: D3.2 (A), J1.A4 (VBUS), J1.A9 (VBUS), J1.B4 (VBUS), J1.B9 (VBUS), R6.1, U2.5 (VBUS)

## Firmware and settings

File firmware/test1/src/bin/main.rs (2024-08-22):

#![no_std]
#![no_main]

extern crate analog_noise_test1;
extern crate cortex_m_rt;
extern crate rtt_target;
extern crate usb_device;
extern crate usbd_serial;

use core::mem::MaybeUninit;

use analog_noise_test1::{dac, epd, ims, touch, usb_serial};
use analog_noise_test1::hal::{self, pac};
use analog_noise_test1::hal::delay::Delay;
use analog_noise_test1::hal::gpio::*;
use analog_noise_test1::hal::prelude::*;
use analog_noise_test1::spi::*;
use rtt_target::rprintln;

use cortex_m_rt::entry;

fn test_pwm(led2: gpiob::PB3<Input<Floating>>, led3: gpiob::PB4<Input<Floating>>, _tim2: pac::TIM2, tim3: pac::TIM3, rcc: &mut hal::rcc::Rcc, delay: &mut Delay) {
    let (_led2, led3) = cortex_m::interrupt::free(move |cs| {
        (
            led2.into_alternate_af2(cs),
            led3.into_alternate_af1(cs),
        )
    });

    //let pwm2 = hal::pwm::tim2(tim2, led2, rcc, 20u32.khz());
    let mut led3 = hal::pwm::tim3(tim3, led3, rcc, 20u32.khz());
    let max_duty = led3.get_max_duty();  // 2400
    led3.set_duty(max_duty / 2);
    led3.enable();
    for _ in 0..4 {
        for i in 0..max_duty {
            led3.set_duty(i);
            delay.delay_ms(1_u16);
        }
    }
}

#[entry]
fn main() -> ! {
    let channels = rtt_target::rtt_init! {
        up: {
            0: {
                size: 1024,
                name: "Terminal"
            }
            1: {
                size: 128,
                // skip data if necessary but only full blocks
                mode: rtt_target::ChannelMode::NoBlockSkip,
                name: "IMS"
            }
        }
        down: {
            0: {
                size: 16,
                name: "Terminal"
            }
            1: {
                size: 16,
                name: "dummy"
            }
        }
    };
    rtt_target::set_print_channel(channels.up.0);
    let num = 42;
    rprintln!("Answer: {}", num);


    let mut dp = pac::Peripherals::take().unwrap();
    let mut cp = cortex_m::peripheral::Peripherals::take().unwrap();
    dp.RCC.apb2enr.modify(|_, w| w.syscfgen().set_bit());  // Enable clock for SYSCFG (used for EXTI?)
    let mut rcc = dp
        .RCC
        .configure()
        .hsi48()
        .enable_crs(dp.CRS)
        .sysclk(48.mhz())
        .pclk(24.mhz())
        .freeze(&mut dp.FLASH);
    let gpioa = dp.GPIOA.split(&mut rcc);
    let gpiob = dp.GPIOB.split(&mut rcc);
    let gpioc = dp.GPIOC.split(&mut rcc);
    let gpiof = dp.GPIOF.split(&mut rcc);

    let mut delay = Delay::new(cp.SYST, &rcc);

    dac::test_dac(dp.DAC, gpioa.pa4, gpioa.pa5, dp.TIM6, &mut rcc);

    test_pwm(gpiob.pb3, gpiob.pb4, dp.TIM2, dp.TIM3, &mut rcc, &mut delay);

    let spi = TimesharedSpi::new(gpiob.pb13, gpiob.pb14, gpiob.pb15, dp.SPI2, &mut rcc);

    // copy SPI into static memory because it will be used by an interrupt handler
    static mut SPI: MaybeUninit<TimesharedSpi> = MaybeUninit::uninit();
    let spi = unsafe { SPI.write(spi) };

    if true {
        let pb12 = gpiob.pb12;  // extract here to avoid moving gpiob into the closure
        let cs = cortex_m::interrupt::free(move |cs| {
            pb12.into_push_pull_output(cs)
        });
        let spidev = spi.make_device(cs);

        let mut ims = ims::IMS::new(spidev, gpioa.pa9);
        if let Err(err) = ims::test_ims(&mut ims) {
            rprintln!("ERROR: {:?}", err);
        }

        touch::test_touch(dp.TSC, &mut rcc, gpioa.pa6, gpioa.pa7, gpioa.pa2, gpioa.pa0);

        ims::start_writing_to_rtt(ims, channels.up.1, &mut dp.SYSCFG, &mut dp.EXTI, &mut cp.NVIC);
    }

    if true {
        let pc15 = gpioc.pc15;
        let cs = cortex_m::interrupt::free(move |cs| {
            pc15.into_push_pull_output(cs)
        });
        // The IMS may be using the SPI. It runs in an interrupt, so we can simply wait for it to be done.
        // We have to do this in a wrapper around the SpiDevice because the display library won't tell us
        // the SPI error code.
        let spidev = RepeatWhenBusy::new(spi.make_device(cs));

        let mut epd = epd::EpaperDisplay::new(
            spidev, gpiof.pf0, gpiof.pf1, gpioc.pc14, &mut delay);
        if let Err(err) = epd::test_epd(&mut epd, &mut delay) {
            rprintln!("ERROR: {:?}", err);
        }
    }

    usb_serial::main(usb_serial::UsbHardware {
        led_pin: gpiob.pb2,
        pin_dm: gpioa.pa11,
        pin_dp: gpioa.pa12,
        usb: dp.USB,
    });
}

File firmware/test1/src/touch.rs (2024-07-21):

// TOUCH1, PA6, TSC_G2_IO3
// TOUCH2, PA7, TSC_G2_IO4
// TOUCH3, PA2, TSC_G1_IO3

use crate::hal::{
    gpio::*,
    gpio::gpioa::*,
    pac,
    rcc::Rcc,
};
use rtt_target::rprintln;

pub fn test_touch(tsc: pac::TSC, rcc: &mut Rcc, touch1: PA6<Input<Floating>>, touch2: PA7<Input<Floating>>, touch3: PA2<Input<Floating>>, pa0: PA0<Input<Floating>>) {
    let mut tsc = crate::hal::tsc::Tsc::tsc(tsc, rcc, None);
    let (mut touch1, mut touch2, mut touch3, mut pa0) = cortex_m::interrupt::free(move |cs| {
        (
            touch1.into_alternate_af3(cs),
            touch2.into_alternate_af3(cs),
            touch3.into_alternate_af3(cs),
            pa0.into_alternate_af3(cs),
        )
    });
    tsc.setup_sample_group(&mut touch2);
    tsc.setup_sample_group(&mut pa0);
    tsc.enable_channel(&mut touch1);
    tsc.enable_channel(&mut touch3);
    tsc.start();
    for _ in 0..4 {
        if let Ok(_) = tsc.acquire() {
            //rprintln!("TOUCH: {}, {}, {}", tsc.read(&mut touch1).unwrap(), tsc.read(&mut touch2).unwrap(), tsc.read(&mut touch3).unwrap());
            rprintln!("TOUCH: {}, {}", tsc.read(&mut touch1).unwrap(), tsc.read(&mut touch3).unwrap());
        }
    }
}

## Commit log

2024-06-10 start with PCB
    [analog-noise-generator.kicad_pcb, analog-noise-generator.kicad_sch]
2024-06-11 fix some violations
    [analog-noise-generator.kicad_pcb, analog-noise-generator.kicad_sch]
2024-06-11 move USB connector to board edge
    We had it in the middle to achieve low thickness near the edges
    but that's no good if we want it to be usable in any kind of case
    (including shrink tube).
    [analog-noise-generator.kicad_pcb]
2024-06-11 shorten the board a bit
    [analog-noise-generator.kicad_pcb, analog-noise-generator.kicad_sch]
2024-06-12 remove negative voltage, add more LCSC part numbers, connect opamps
    [analog-noise-generator.kicad_pcb, analog-noise-generator.kicad_sch]
2024-06-16 start routing
    [analog-noise-generator.kicad_pcb, analog-noise-generator.kicad_sch]
2024-06-16 move all top parts onto PCB
    [analog-noise-generator.kicad_pcb]
2024-06-16 move PCB files
    [analog-noise-generator.kicad_pcb, analog-noise-generator.kicad_sch]
2024-06-16 fix ERC issues
    [analog-noise-generator.kicad_sch]
2024-06-16 generate files for JLC
    [analog-noise-generator.kicad_sch, analog-noise-generator_bom_jlc.csv, analog-noise-generator_bom_lcsc_non_pcba.csv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]
2024-06-20 switch to four layers and continue routing
    [analog-noise-generator.kicad_pcb, analog-noise-generator.kicad_sch]
2024-06-21 finish routing
    [analog-noise-generator.kicad_pcb, analog-noise-generator.kicad_sch]
2024-06-21 improve silk
    [analog-noise-generator.kicad_pcb]
2024-06-23 add some LEDs
    [analog-noise-generator.kicad_pcb, analog-noise-generator.kicad_sch]
2024-06-28 add testpoint for 3.3V
    [analog-noise-generator.kicad_pcb, analog-noise-generator.kicad_sch]
2024-06-28 generate PCB files
    [analog-noise-generator_bom_jlc.csv, analog-noise-generator_bom_lcsc_non_pcba.csv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]
2024-06-28 fix some issues for JLC
    - increase some clearances that were marked as "danger" in their DFM
    - change value of C12, so it won't be grouped with the incompatible 100 nF caps
    - add image to README
    - rotate U2 in CPL file
    [analog-noise-generator.kicad_pcb, analog-noise-generator.kicad_sch, analog-noise-generator_bom_jlc.csv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]
2024-07-19 try to add defmt-rtt
    This doesn't work so well because we
    cannot apply our bootloader workarounds
    when running under probe-rs and we
    couldn't get OpenOCD to read from RTT.
    [main.rs]
2024-07-20 try to use RTT for custom data
    OpenOCD finds the RTT control block and
    often it prints some data to the TCP socket
    but that seems to be some random
    memory rather than the buffer.
2024-07-20 fixup: last argument for `monitor rtt setup` was wrong
    [ims.rs]
2024-07-20 test PWM for one LED
2024-07-21 use builtin waveform generators for DAC (triangle and noise)
    [dac.rs, main.rs, main2.rs]
2024-07-21 change main2 to use less power
2024-08-03 add sine wave with some noise
    [dac.rs, main2.rs]
2024-08-03 add errata for output filter
2024-08-22 implement DelayNs, GPIO and SPI for embedded-hal 1.0.0
2024-08-22 use embedded-hal-bus to share the SPI
2024-08-22 retry SPI access for epaper if IMS is using the bus
2024-08-22 copy SPI instance into static memory for use in interrupt handler
